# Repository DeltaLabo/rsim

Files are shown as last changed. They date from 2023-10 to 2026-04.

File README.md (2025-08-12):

Room sound intensity meter
============
## DeltaLAB - Instituto Tecnológico de Costa Rica

### Developers

* [Juan J. Rojas](mailto:juan.rojas@itcr.ac.cr)
* [Anthony Arguedas](mailto:antarguedas@estudiantec.r)
* [Josué Morera](mailto:josuemr0106@estudiantec.cr)

### Toolset
* Code, Documentation, Task Management: GitHub
* CAD, CAM, PCB: Fusion 360
* Systems Engineering: Capella

### What is this repository for?

* This repository was created to develop an ESP32-based ambient noise level meter.

### Microcontroller info

* Model: ESP32-S3 DevKit-C1 
* [Documentation page](https://docs.espressif.com/projects/esp-idf/en/stable/esp32s3/hw-reference/esp32s3/user-guide-devkitc-1.html)

### Microphone info

* Model: INMP441 I2S digital microphone
* [Datasheet](https://invensense.tdk.com/wp-content/uploads/2015/02/INMP441.pdf)

### How do I set up?

* Install Git
* Install Arduino IDE
* Follow these [instructions](https://docs.espressif.com/projects/arduino-esp32/en/latest/installing.html) to set up the ESP32-S3 in the Arduino IDE
* Connect the components as shown in the diagram found in [`schematic_diagram.pdf`](https://github.com/DeltaLabo/rsim/blob/main/schematic_diagram.pdf)

* Clone this repo and upload [`main.ino`](https://github.com/DeltaLabo/rsim/tree/main/main) to the ESP32

### Contribution guidelines ###

* If you want to propose a change or need to modify the code for any reason first clone this [repository](https://github.com/DeltaLabo/rsim) to your PC and create a new branch for your changes. Once your changes are complete and fully tested ask the administrator permission to push this new branch into the source.
* If you just want to do local changes instead you can download a zip version of the repository and do all changes locally in your PC.

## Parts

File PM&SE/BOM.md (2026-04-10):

# Bill of Materials

| Link | Quantity | Units |
|--|--|--|
| https://www.digikey.com/en/products/detail/sunled/XZFBBM2CRKM2DGZ157W/16592254 | 10 | Unit |
| https://www.digikey.com/en/products/detail/adafruit-industries-llc/5180/15287551 | 3 | Unit |
| https://a.co/d/0hQVEhGn | 1 | Unit |
| https://a.co/d/0fQg39To | 1 | Unit |

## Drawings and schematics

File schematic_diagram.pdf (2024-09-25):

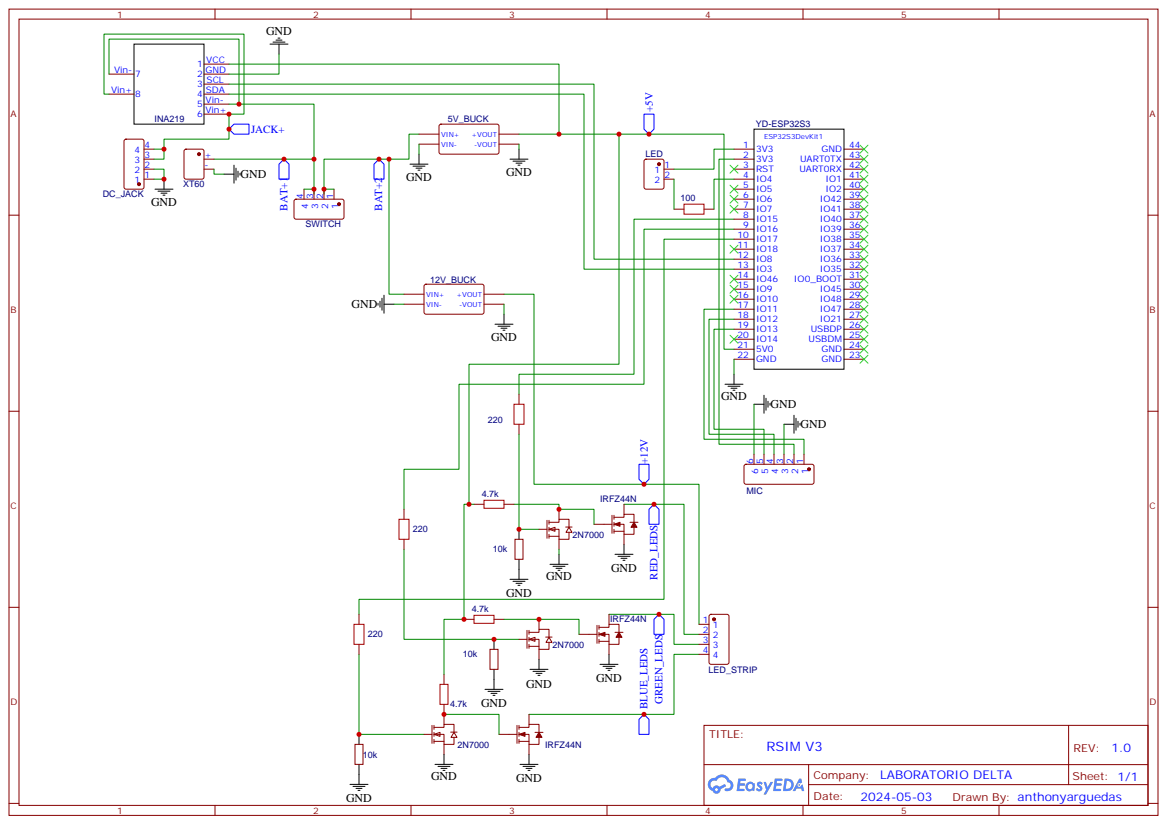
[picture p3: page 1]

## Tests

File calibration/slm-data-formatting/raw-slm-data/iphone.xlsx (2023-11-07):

s_unwted |  | f_unwted |  | f_wted |  | s_wted
esp | slm | esp | slm | esp | slm | esp | slm
72.2 | 70 | 72 | 70.6 | 70 | 68.7 | 70.2 | 69.2
72.1 | 70 | 71.9 | 69.9 | 71.3 | 69.7 | 72.1 | 69.6
72.1 | 70.1 | 71.9 | 70 | 71.3 | 69.8 | 72 | 69.7
72.1 | 70.6 | 71.9 | 69.2 | 71.2 | 70 | 72.1 | 69.9
72 | 70.3 | 72 | 69.6 | 71 | 69.6 | 72.3 | 69.6
72.1 | 70.4 | 72 | 69.2 | 71 | 69.5 | 72.1 | 70
72 | 70.3 | 71.9 | 69.3 | 71 | 69.6 | 72.2 | 69.6
72 | 70.4 | 72.2 | 69.6 | 71.9 | 69.4 | 72.1 | 69.7
72 | 70.3 | 72.3 | 69.9 | 71.8 | 69.3 | 72 | 69.8
72.1 | 70.4 | 72.1 | 69.7 | 71.4 | 69.4 | 72.1 | 69.6
72.2 | 70.3 | 72.2 | 69.7 | 71.7 | 69.4 | 72 | 69.7
72.2 | 70.3 | 72.1 | 70 | 72.1 | 69.4 | 72.1 | 69.7
72.2 | 70.2 | 72 | 69.6 |  |  | 72 | 69.6
72.1 | 70.4 | 72.1 | 69.6 |  |  | 72 | 69.7
72.3 | 70.5 | 72.2 | 66.4 |  |  | 72 | 69.7
71.7 | 70.8 |  |  |  |  | 72 | 69.7
 |  |  |  |  |  | 72 | 70.6
 |  |  |  |  |  | 72.1 | 69.8
 |  |  |  |  |  | 72.1 | 69.7
 |  |  |  |  |  | 72.2 | 69.8
 |  |  |  |  |  | 72.2 | 69.7
 |  |  |  |  |  | 72.1 | 69.8
 |  |  |  |  |  | 72.1 | 70.3
 |  |  |  |  |  | 72.2 | 69.8
 |  |  |  |  |  | 72.2 | 69.7

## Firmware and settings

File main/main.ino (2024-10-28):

#include <Arduino.h>
#include "driver/i2s.h"
#include <stdint.h>

#include "src/slm.h"
#include "src/adafruit-io.h"
#include "src/battery-checker.h"

#include "src/checks.h"


// Set to enable/disable functionality
bool USE_BATTERY = true;
bool USE_LOGGING = false;


QueueHandle_t samples_queue;
QueueHandle_t logging_queue;


// FreeRTOS priority and stack sizes (in 32-bit words) 
#define I2S_TASK_PRI 5
#define I2S_TASK_STACK 4096
#define LEQ_TASK_PRI 5
#define LEQ_TASK_STACK 8192
#define BAT_TASK_PRI 1
#define BAT_TASK_STACK 4096
#define WIFI_TASK_PRI 1
#define WIFI_TASK_STACK 4096
#define LOGGER_TASK_PRI 3
#define LOGGER_TASK_STACK 8192


void setup() {
  setCpuFrequencyMhz(240);

  // Init serial for logging
  Serial.begin(115200);

  if (runtimeChecks() == false) {
    Serial.println("[ERROR]: Cannot start with invalid parameters.");
    while (true) {} // Halt indefinitely
  }

  // Create FreeRTOS queue
  samples_queue = xQueueCreate(100, sizeof(float));

  if (USE_BATTERY == true) {
    xTaskCreatePinnedToCore(battery_checker_task, "Battery Checker", BAT_TASK_STACK, NULL, BAT_TASK_PRI, NULL, 1);
  } else {
    Serial.println("[INFO] [POWER]: Battery checking disabled.");
  }

  if (USE_LOGGING == true) {
    // Create the WiFi connection task and pin it to the second core (ID=1)
    xTaskCreatePinnedToCore(wifi_checker_task, "WiFi Checker", WIFI_TASK_STACK, NULL, WIFI_TASK_PRI, NULL, 1);

    // Initialize the logging queue
    logging_queue = xQueueCreate(LOGGING_QUEUE_SIZE, sizeof(LogData));

    // Create the logger task and pin it to the second core (ID=1)
    xTaskCreatePinnedToCore(logger_task, "Logger", LOGGER_TASK_STACK, NULL, LOGGER_TASK_PRI, NULL, 1);
  } else {
    Serial.println("[INFO] [LOGGING]: Logging disabled.");
  }
  // Create the mic reader task and pin it to the first core (ID=0)
  xTaskCreatePinnedToCore(mic_i2s_reader_task, "Mic I2S Reader", I2S_TASK_STACK, NULL, I2S_TASK_PRI, NULL, 0);

  // Create the Leq calculator task and pin it to the second core (ID=1)
  xTaskCreatePinnedToCore(leq_calculator_task, "Leq Calculator", LEQ_TASK_STACK, NULL, LEQ_TASK_PRI, NULL, 1);


  vTaskDelay(pdMS_TO_TICKS(1000)); // Safety
}

void loop() {
  // Execution will never reach this point since we're using FreeRTOS
}

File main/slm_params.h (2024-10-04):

// Parameter file for the dB meter
// These are in a separate file to avoid updating the versioned main.ino file just to change them

#ifndef SLM_PARAMS_H
#define SLM_PARAMS_H

// Periods
#define LOGGING_PERIOD 16.0 // second(s)
#define RTC_UPDATE_PERIOD 3600000 // millisecond(s), 1 hour
#define ESP32_RESTART_PERIOD 86400000 // millisecond(s), 24 hours
#define BATTERY_CHECK_PERIOD 60000 // millisecond(s), 1 minute

// Indicator color definitions
#define RED 2
#define YELLOW 1
#define GREEN 0

// Amount of measurements to calculate the average color over
#define COLOR_WINDOW_SIZE 5

#define LEDC_FREQ 5000 // Hz
#define LEDC_RESOLUTION 8 // bits

// Power states
#define LOW_BATTERY 0
#define ENOUGH_BATTERY 1
#define CHARGING 2

// Power constants
#define MIN_CHARGING_CURRENT 200 // mA
#define MIN_CHARGED_VOLTAGE 12.8 // V

// Comment to disable
//#define USE_BATTERY

//
// SLM Configuration
//

#define LEQ_PERIOD        2.0      // second(s)
#define WEIGHTING         A_weighting // 'A_weighting' 'C_weighting' or 'None' (Z_weighting)
#define LEQ_UNITS         "LAeq"      // customize based on above weighting used
#define DB_UNITS          "dBA"       // customize based on above weighting used
#define MIC_OFFSET_DB     1.3         // Offset (sine-wave RMS vs. dBFS). Modify this value for linear calibration.

#define GREEN_UPPER_LIMIT  57.0 // dBA, maximum noise level for which the indicator stays green
#define YELLOW_UPPER_LIMIT 70.0 // dBA, maximum noise level for which the indicator stays yellow

#endif

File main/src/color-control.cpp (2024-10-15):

#include "color-control.h"


// Previous local color indication
// Used to avoid setting the LEDs to the same color
// they already were
// Initialized to a null value
int prevColor = -1;

// Last measurements collected, converted to color
int colorArray[COLOR_WINDOW_SIZE];
// Flag to reset the values stored in the array
bool initColorArray = true;


// Init pins used to control the color indicator
void initColorPins() {
  // ledc (PWM) frequency and resolution setup
  ledcAttach(RED_LED_PIN, LEDC_FREQ, LEDC_RESOLUTION);
  ledcAttach(GREEN_LED_PIN, LEDC_FREQ, LEDC_RESOLUTION);
  ledcAttach(BLUE_LED_PIN, LEDC_FREQ, LEDC_RESOLUTION);

  analogWrite(RED_LED_PIN, 255);
  analogWrite(GREEN_LED_PIN, 255);
  analogWrite(BLUE_LED_PIN, 255);
}

// Convert a sound measurement in decibels to a color code
int leqToColor(float Leq_dB){
  if (Leq_dB < GREEN_UPPER_LIMIT) {
    return GREEN;
  }
  else if (Leq_dB < YELLOW_UPPER_LIMIT) {
    return YELLOW;
  }
  else {
    return RED;
  }
}

void resetArray(int* array, int arraySize, int value) {
  // Populate the array with copies of the same value
  for (int i=0; i<arraySize; i++) {
    array[i] = value;
  }
}

void appendToArray(int* array, int arraySize, int newValue) {
  // Append the new value to the array
  for (int i=0; i<arraySize-1; i++) {
    array[i] = array[i+1];
  }
  array[arraySize-1] = newValue;
}

int updateColorArray(int currentColor) {
  if (initColorArray) {
    resetArray(colorArray, COLOR_WINDOW_SIZE, currentColor);
    initColorArray = false;
    // Don't change the current color
    return currentColor;
  } else {
    // The array must be reset whenever a new measurement is lower
    // than the last one
    if (currentColor < colorArray[COLOR_WINDOW_SIZE-1]) {
      resetArray(colorArray, COLOR_WINDOW_SIZE, currentColor);
      // Don't change the current color
      return currentColor;
    } else {
      if (currentColor == RED && colorArray[COLOR_WINDOW_SIZE-1] == GREEN) {
        appendToArray(colorArray, COLOR_WINDOW_SIZE, currentColor);

        return currentColor;
      } else if (currentColor == RED && colorArray[COLOR_WINDOW_SIZE-1] == RED) {
        appendToArray(colorArray, COLOR_WINDOW_SIZE, currentColor);

        return currentColor;
      } else {
        appendToArray(colorArray, COLOR_WINDOW_SIZE, currentColor);

        // Calculate the average color
        // This is possible since colors are represented by integers in the range 0-2
        float averageColor = 0.0;
        for (int i=0; i<COLOR_WINDOW_SIZE; i++) {
          averageColor += colorArray[i];
        }
        averageColor /= float(COLOR_WINDOW_SIZE);

        // Convert the floating point average to one of the defined colors
        if (averageColor < 0.5) { // 0.0 <= averageColor < 0.5
          return GREEN;
        } else if (averageColor < 1.4) { // 0.5 <= averageColor < 1.4
          return YELLOW;
        } else { // averageColor >= 1.4
          return RED;
        }
      }
    }
  }
}

// Update the LED color
void setLEDColor(int color){
  if (color != prevColor) {
    prevColor = color;

    analogWrite(GREEN_LED_PIN, 255);
    analogWrite(RED_LED_PIN, 255);
    analogWrite(BLUE_LED_PIN, 255);

    if(color == RED){
      analogWrite(RED_LED_PIN, 0);
    }
    else if(color == GREEN){
      analogWrite(GREEN_LED_PIN, 0);
    }
    else { // color == YELLOW
      analogWrite(GREEN_LED_PIN, 100);
      analogWrite(RED_LED_PIN, 0);
    }
  }
}

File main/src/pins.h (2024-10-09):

#ifndef PINS_H
#define PINS_H

#define I2S_WS  13
#define I2S_SCK 12
#define I2S_SD  11

#define RED_LED_PIN 15
#define GREEN_LED_PIN 16
#define BLUE_LED_PIN 17

#define CHARGER_LED_PIN 4

#define INA_SDA 3
#define INA_SCL 8

#endif

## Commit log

2023-08-04 Rewrite IIR filter in C++
    sos-iir-filter-esp32.h is the original IIR filter.
    sos-iir-filter-esp32.h is the same filter but written in C++.
2023-09-23 Add LED indicator function
    [3-led-indicator.fzz]
2023-10-02 Port SOS filters to RISC-V with floats
2023-10-05 Add LED indicator toggle
2023-10-07 Print dB values to OLED display
2023-10-07 Fix overload and floor compensation
    [slm_params.h]
2023-10-24 Use xtensa filters on S3
2023-10-26 Add calibration scripts
2023-10-26 Convert offset.py to .ipynb
    [offset.csv]
2023-10-31 Convert offset calibration script to ipynb
2023-10-31 Driver control
    Archivo .zip con librería requerida y código .ino con la conexiones de los pines del ESP32S3 al driver y los códigos RGB de los respectivos colores.
2023-11-05 Separate data collection and analysis notebooks
    [offset.csv]
2023-11-07 Generate offset calibration results
2023-11-07 Add offset with respect to NIOSH SLM
    [iphone.xlsx]
2023-11-16 Run 3M calibration
2023-11-17 Port BLE receiver to Arduino
2023-11-18 Add LED strip control
2023-11-25 Change period to 8s, with conditional switching
2023-12-02 Build time progression from freq samples
2023-12-02 Test code for calibration
2023-12-02 Calibration and results interpretation
2023-12-02 Update params after calibration
2024-01-03 Update pin numbers
2024-02-28 Update pin definitions for YD ESP
2024-05-08 Remove LED Driver library from main project
2024-05-08 Add LED Strip Driver test
2024-05-20 Fix include file guards
    [rtc.cpp, slm_params.h]
2024-06-07 Create YD ESP32 test code
2024-06-21 Implement ledc
2024-08-17 Update pins for PCB
2024-08-31 Implement battery monitoring
2024-10-01 Remove unused filters
2024-10-01 Migrate to ledc API 3.0.5
2024-10-03 Fix invalid memory access
    [main.ino]
2024-10-05 Move filters to src folder
2024-10-08 Move battery checker functionality to separate file
2024-10-10 Fix WiFi checker delay
    [adafruit-io.cpp]
2024-10-15 Turn all LEDs off at startup
2024-10-16 Revert "Implement async HTTP POST"
    This reverts commit a6c1762cedfead9ae88deba171a715d210eb3b59.
    [adafruit-io.cpp, main.ino]
2024-10-21 Switch to runtime checks
2024-10-21 Fix feed key corruption
    [adafruit-io.cpp, slm.cpp]
